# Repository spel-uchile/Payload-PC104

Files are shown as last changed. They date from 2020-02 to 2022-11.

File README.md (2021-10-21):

# Payload-PC104 #

This repository contains schematics and footprints of the PC104 standard for CubeSats' payloads. 
These designs are compatible with Eagle and KiCad PCB design software.
The footprints have also a suggested PCB boundary that facilitates the cable management of the CubeSat.

# KiCAD #

The KiCAD's schematic includes all the necessary pins assignments to speedup the payload design. The footprint already has the edge cuts done and it follows the PC104 specification.

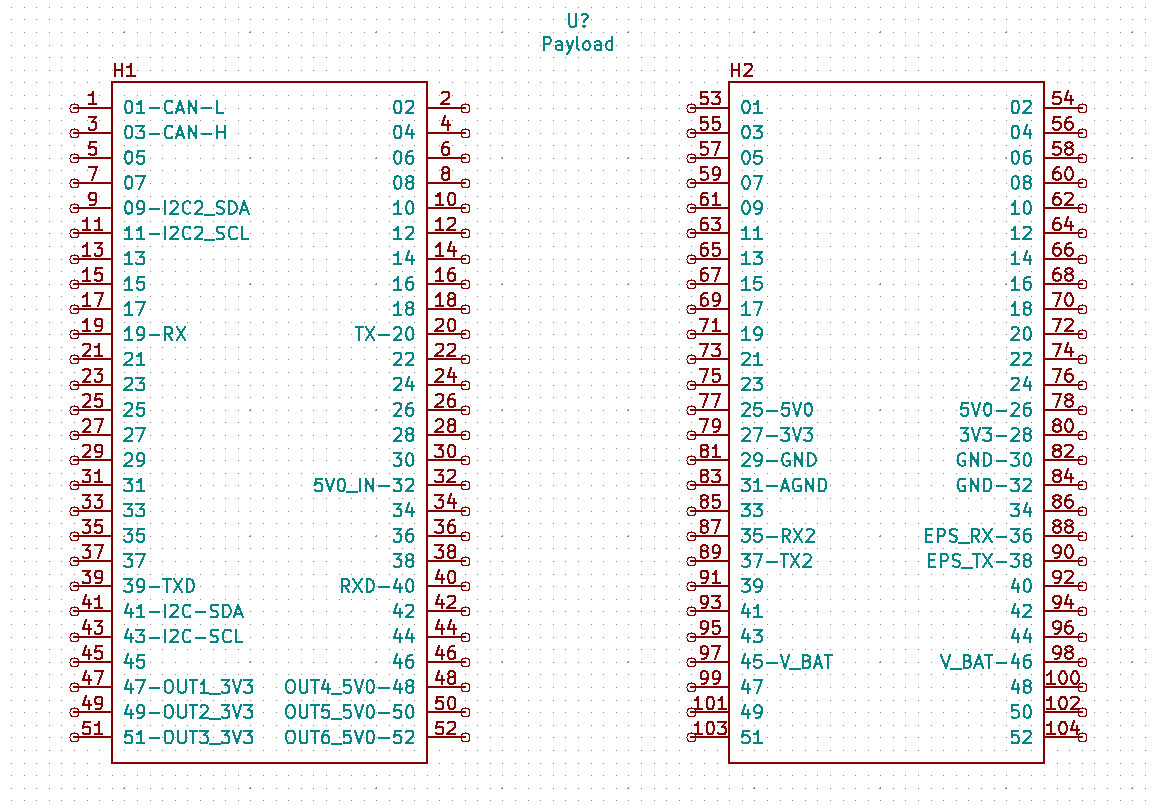
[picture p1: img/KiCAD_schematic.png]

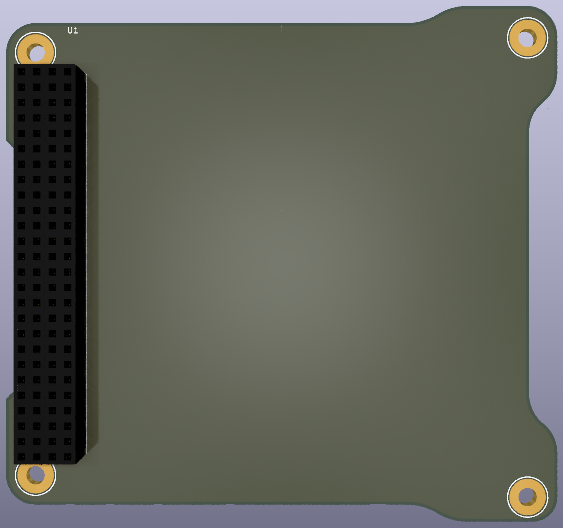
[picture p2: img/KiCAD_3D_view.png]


# Last update 10/21/2021# 
Output voltage pin update on StackBreakout with Molex picoBlade

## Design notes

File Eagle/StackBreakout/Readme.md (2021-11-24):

Readme - Stack Breakout

Stack Breakout - 4 capas

Historial

2021-11-24
Correción de error en conexión I2C v2. Los pines actuales son SCL (H1.9), SDA (H1.11). 
La versión anterior tiene las conexiones invertidas, es decir, el pin SCL estaba en H1.11, y SDA en H1.9.

2021-10-21
Se actualizan el orden los OUT pin de voltaje de acuerdo a la configuración de pinout de SPEL.

2020-08-12
Se incorpora conector con conexión I2C y UART.

2020-07-27 - V1.0
Se genera la placa de acuerdo a los diseños (dxf) enviados por Elías Obreque.
Se genera la placa usando cuatro capas
Se configurar parámetros genéricos (y más comunes) para el chequeo de errores (DRC - Design Rule Check)

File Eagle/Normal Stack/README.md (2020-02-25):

# Normal stack-PC104
This folder contains schematics and footprints of the PC104 standard for CubeSats' payloads with diferent dimension pad in the Stack component (only the pins used in SUCHAI project are edited)

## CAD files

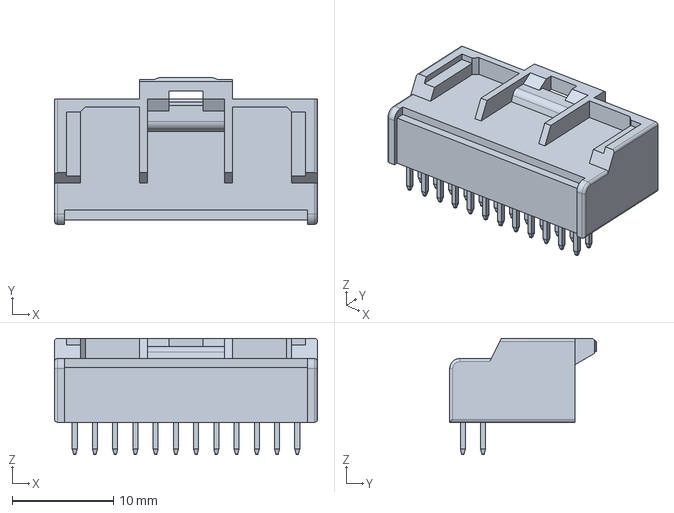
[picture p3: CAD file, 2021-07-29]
Eagle/StackBreakout/StackBreakoutConnection_4layers_V1.0_with_connector/MolexP24/2086592440.stp
26.0 x 14.5 x 11.5 mm

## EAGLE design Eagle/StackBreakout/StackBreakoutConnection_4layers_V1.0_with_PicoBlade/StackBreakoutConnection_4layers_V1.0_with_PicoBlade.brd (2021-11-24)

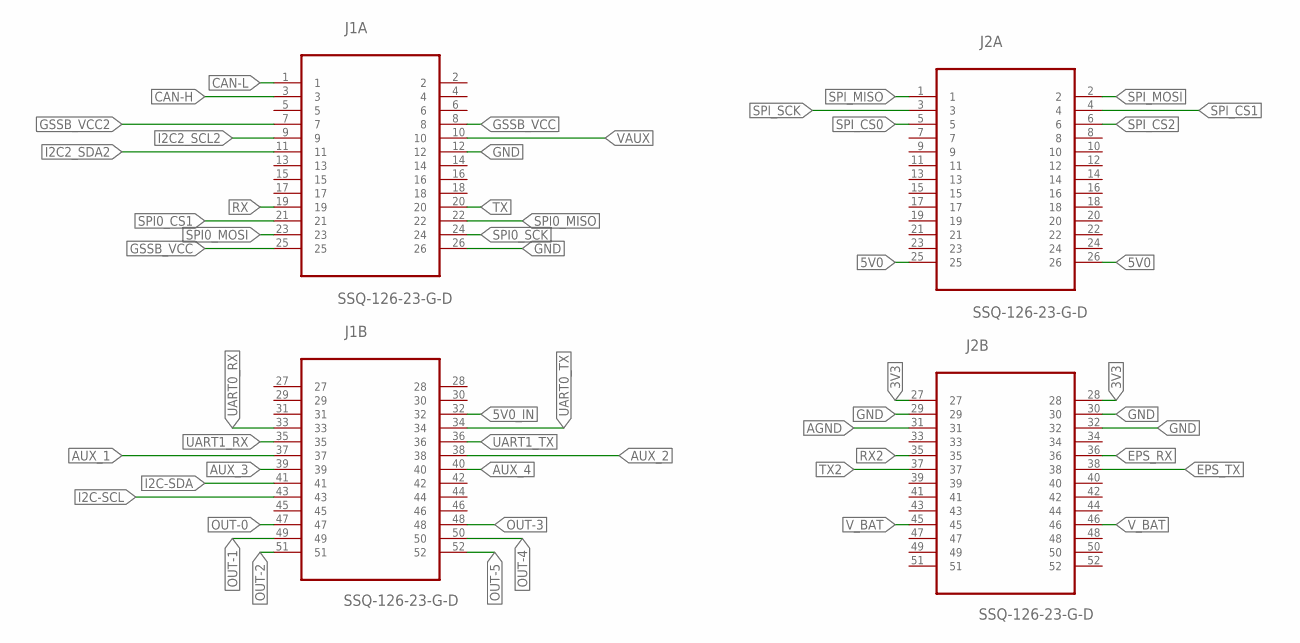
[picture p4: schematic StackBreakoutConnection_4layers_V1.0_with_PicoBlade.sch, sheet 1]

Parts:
J1, J2: SSQ-126-23-G-D; SAMTEC_SSQ-126-23-G-D

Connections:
3V3: J2.27, J2.28; also elsewhere on the board
5V0: J2.25, J2.26; also elsewhere on the board
5V0_IN: J1.32; also elsewhere on the board
AGND: J2.31; also elsewhere on the board
AUX_1: J1.37; also elsewhere on the board
AUX_2: J1.38; also elsewhere on the board
AUX_3: J1.39; also elsewhere on the board
AUX_4: J1.40; also elsewhere on the board
CAN-H: J1.3; also elsewhere on the board
CAN-L: J1.1; also elsewhere on the board
EPS_RX: J2.36; also elsewhere on the board
EPS_TX: J2.38; also elsewhere on the board
GND: J1.12, J1.26, J2.29, J2.30, J2.32; also elsewhere on the board
GSSB_VCC: J1.8, J1.25; also elsewhere on the board
GSSB_VCC2: J1.7; also elsewhere on the board
I2C2_SCL2: J1.9; also elsewhere on the board
I2C2_SDA2: J1.11; also elsewhere on the board
I2C-SCL: J1.43; also elsewhere on the board
I2C-SDA: J1.41; also elsewhere on the board
OUT-0: J1.47; also elsewhere on the board
OUT-1: J1.49; also elsewhere on the board
OUT-2: J1.51; also elsewhere on the board
OUT-3: J1.48; also elsewhere on the board
OUT-4: J1.50; also elsewhere on the board
OUT-5: J1.52; also elsewhere on the board
RX: J1.19
RX2: J2.35
SPI0_CS1: J1.21; also elsewhere on the board
SPI0_MISO: J1.22; also elsewhere on the board
SPI0_MOSI: J1.23; also elsewhere on the board
SPI0_SCK: J1.24; also elsewhere on the board
SPI_CS0: J2.5
SPI_CS1: J2.4
SPI_CS2: J2.6
SPI_MISO: J2.1
SPI_MOSI: J2.2
SPI_SCK: J2.3
TX: J1.20
TX2: J2.37
UART0_RX: J1.33; also elsewhere on the board
UART0_TX: J1.34; also elsewhere on the board
UART1_RX: J1.35; also elsewhere on the board
UART1_TX: J1.36; also elsewhere on the board
VAUX: J1.10; also elsewhere on the board
V_BAT: J2.45, J2.46; also elsewhere on the board

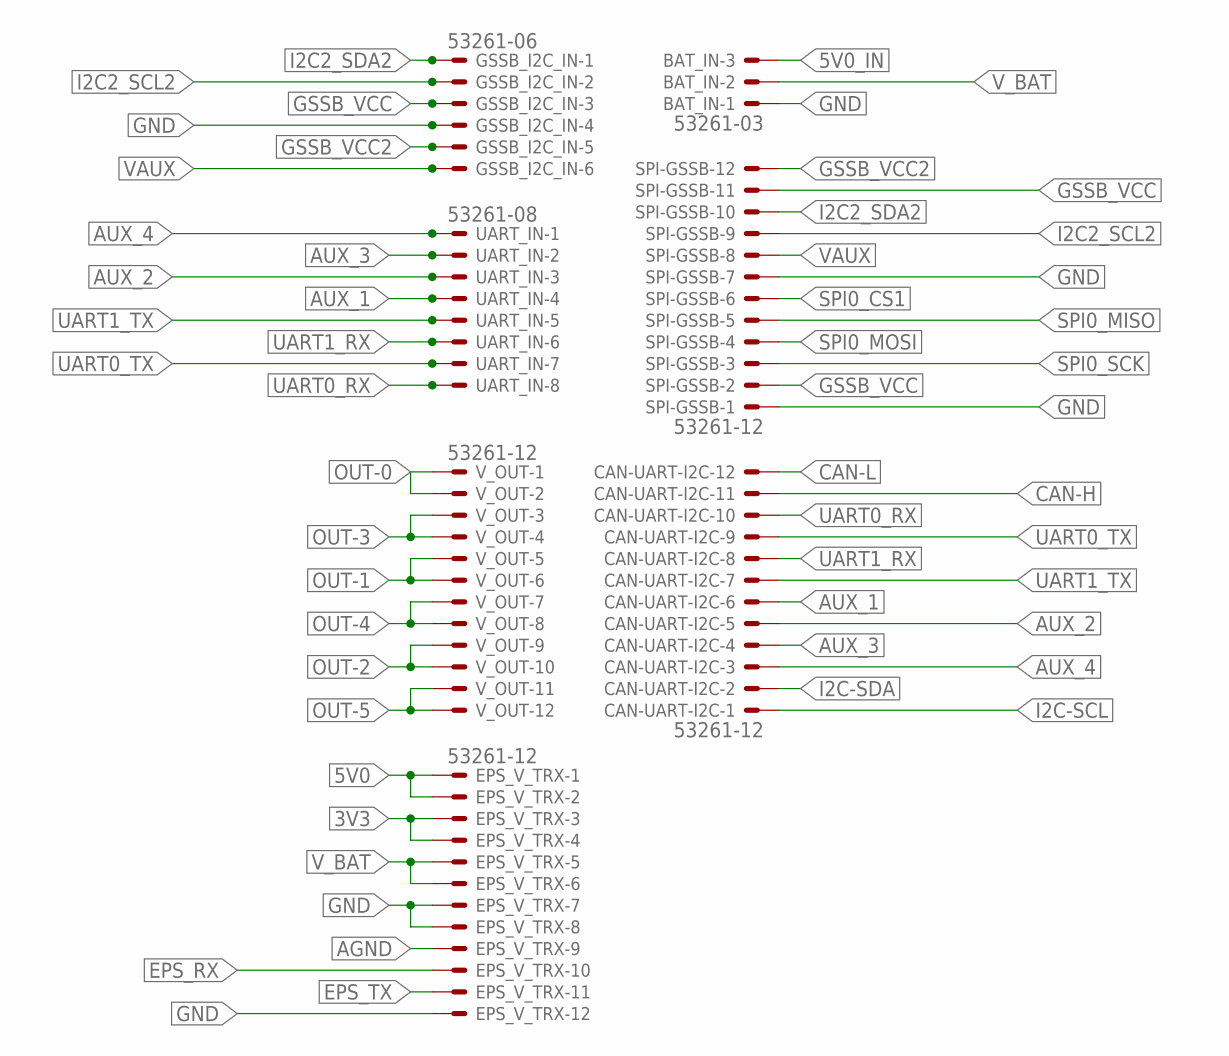
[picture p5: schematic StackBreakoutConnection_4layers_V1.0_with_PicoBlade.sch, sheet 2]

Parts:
BAT_IN: 53261-03
CAN-UART-I2C: 53261-12
EPS_V_TRX: 53261-12
GSSB_I2C_IN: 53261-06
SPI-GSSB: 53261-12
UART_IN: 53261-08
V_OUT: 53261-12

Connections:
3V3: EPS_V_TRX.3, EPS_V_TRX.4; also elsewhere on the board
5V0: EPS_V_TRX.1, EPS_V_TRX.2; also elsewhere on the board
5V0_IN: BAT_IN.3; also elsewhere on the board
AGND: EPS_V_TRX.9; also elsewhere on the board
AUX_1: CAN-UART-I2C.6, UART_IN.4; also elsewhere on the board
AUX_2: CAN-UART-I2C.5, UART_IN.3; also elsewhere on the board
AUX_3: CAN-UART-I2C.4, UART_IN.2; also elsewhere on the board
AUX_4: CAN-UART-I2C.3, UART_IN.1; also elsewhere on the board
CAN-H: CAN-UART-I2C.11; also elsewhere on the board
CAN-L: CAN-UART-I2C.12; also elsewhere on the board
EPS_RX: EPS_V_TRX.10; also elsewhere on the board
EPS_TX: EPS_V_TRX.11; also elsewhere on the board
GND: BAT_IN.1, EPS_V_TRX.7, EPS_V_TRX.8, EPS_V_TRX.12, GSSB_I2C_IN.4, SPI-GSSB.1, SPI-GSSB.7; also elsewhere on the board
GSSB_VCC: GSSB_I2C_IN.3, SPI-GSSB.2, SPI-GSSB.11; also elsewhere on the board
GSSB_VCC2: GSSB_I2C_IN.5, SPI-GSSB.12; also elsewhere on the board
I2C2_SCL2: GSSB_I2C_IN.2, SPI-GSSB.9; also elsewhere on the board
I2C2_SDA2: GSSB_I2C_IN.1, SPI-GSSB.10; also elsewhere on the board
I2C-SCL: CAN-UART-I2C.1; also elsewhere on the board
I2C-SDA: CAN-UART-I2C.2; also elsewhere on the board
OUT-0: V_OUT.1, V_OUT.2; also elsewhere on the board
OUT-1: V_OUT.5, V_OUT.6; also elsewhere on the board
OUT-2: V_OUT.9, V_OUT.10; also elsewhere on the board
OUT-3: V_OUT.3, V_OUT.4; also elsewhere on the board
OUT-4: V_OUT.7, V_OUT.8; also elsewhere on the board
OUT-5: V_OUT.11, V_OUT.12; also elsewhere on the board
SPI0_CS1: SPI-GSSB.6; also elsewhere on the board
SPI0_MISO: SPI-GSSB.5; also elsewhere on the board
SPI0_MOSI: SPI-GSSB.4; also elsewhere on the board
SPI0_SCK: SPI-GSSB.3; also elsewhere on the board
UART0_RX: CAN-UART-I2C.10, UART_IN.8; also elsewhere on the board
UART0_TX: CAN-UART-I2C.9, UART_IN.7; also elsewhere on the board
UART1_RX: CAN-UART-I2C.8, UART_IN.6; also elsewhere on the board
UART1_TX: CAN-UART-I2C.7, UART_IN.5; also elsewhere on the board
VAUX: GSSB_I2C_IN.6, SPI-GSSB.8; also elsewhere on the board
V_BAT: BAT_IN.2, EPS_V_TRX.5, EPS_V_TRX.6; also elsewhere on the board

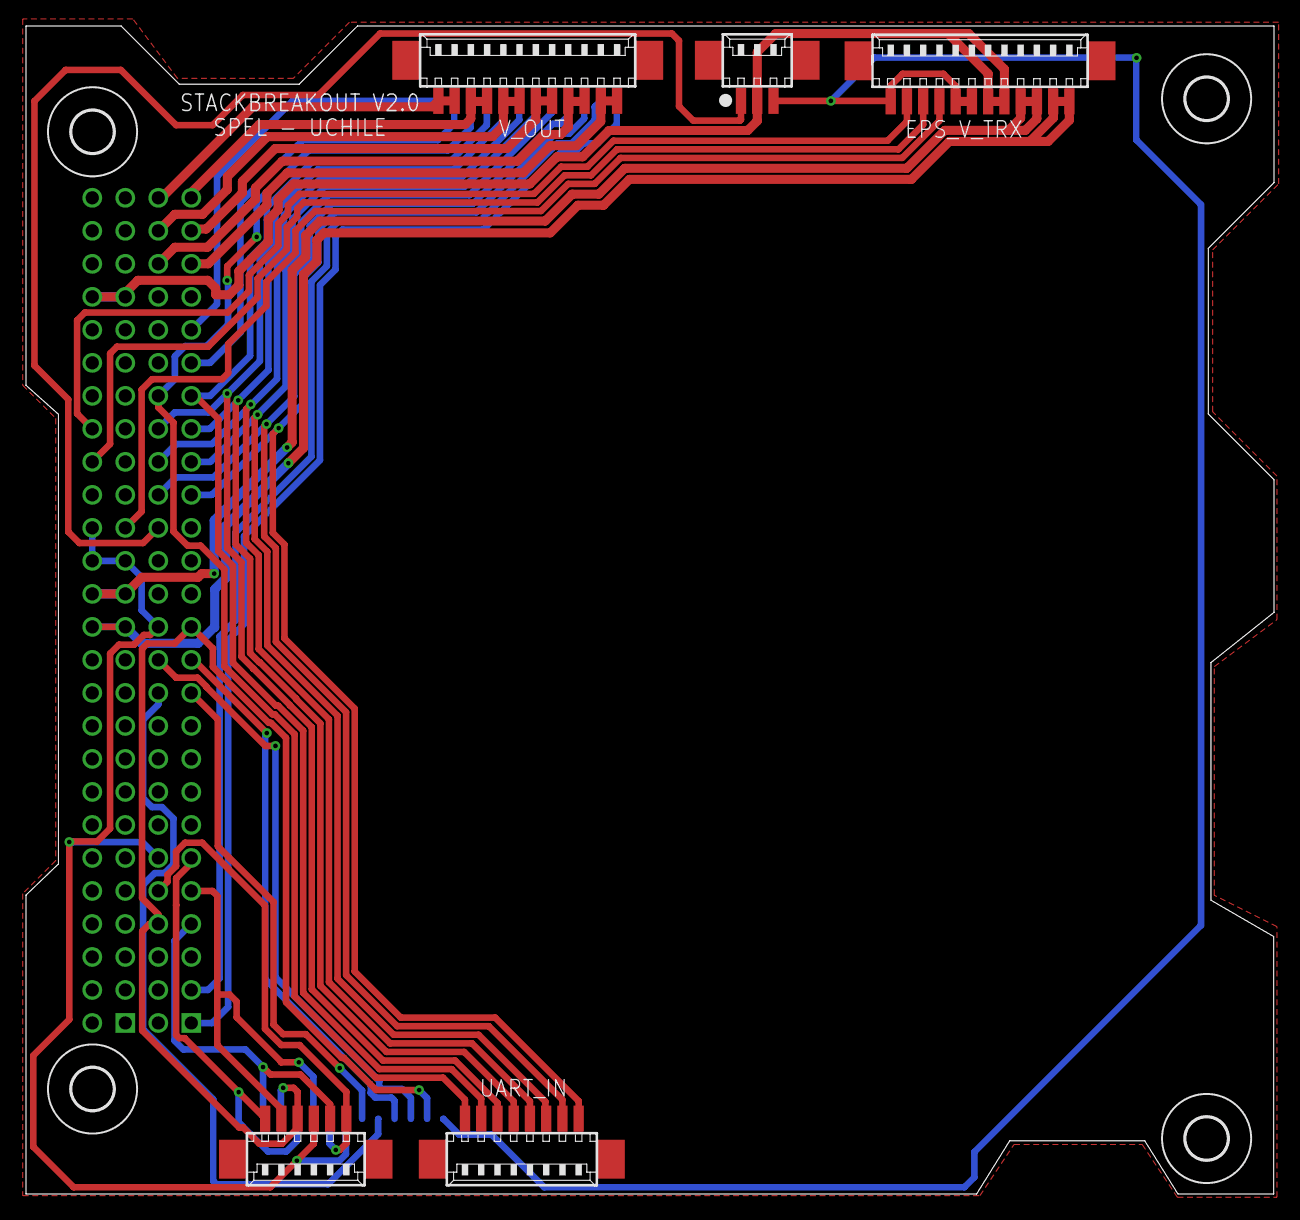
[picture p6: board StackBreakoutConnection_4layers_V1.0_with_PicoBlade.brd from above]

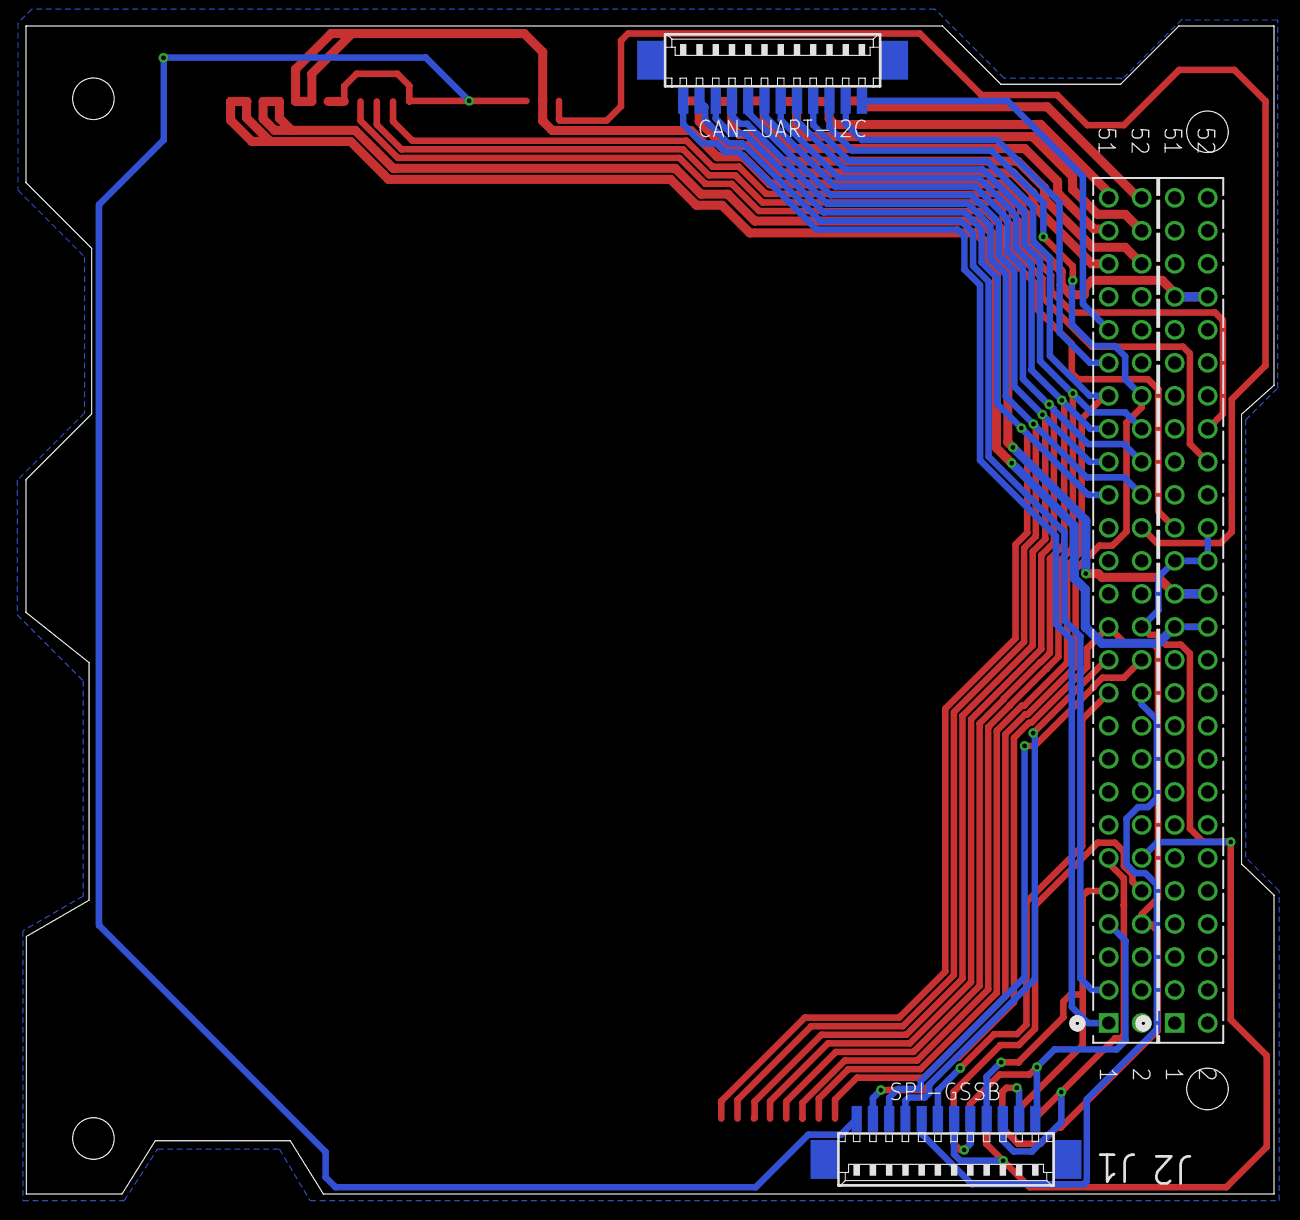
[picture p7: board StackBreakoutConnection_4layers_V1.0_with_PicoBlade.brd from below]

Board: 4 copper layers, 96.0 x 89.9 mm, 13 parts (4 on the bottom side), 35 nets.

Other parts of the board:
GND: 3,2
U$1, U$2, U$4: 3,2

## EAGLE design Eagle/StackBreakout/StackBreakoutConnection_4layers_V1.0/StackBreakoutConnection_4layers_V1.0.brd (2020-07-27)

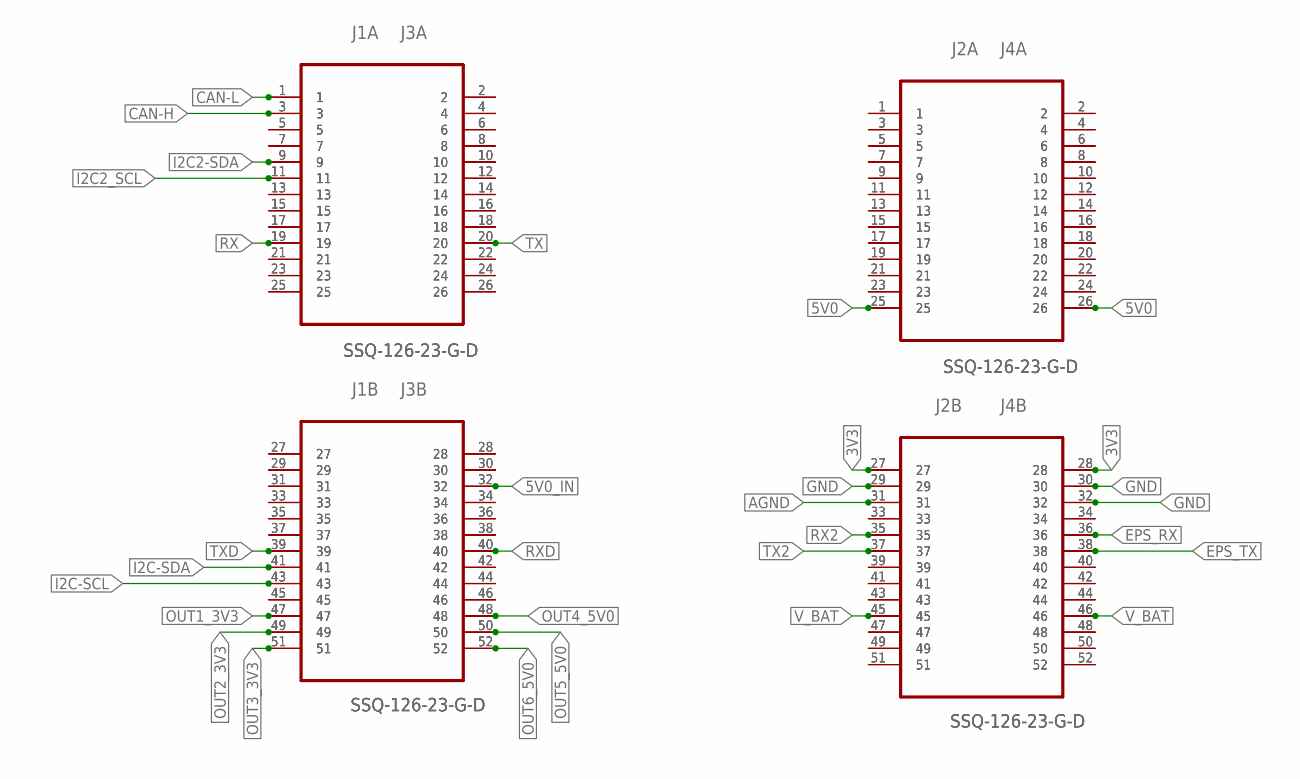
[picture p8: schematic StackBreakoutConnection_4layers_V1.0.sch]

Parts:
J1, J2, J3, J4: SSQ-126-23-G-D; SAMTEC_SSQ-126-23-G-D

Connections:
3V3: J2.27, J2.28, J4.27, J4.28
5V0: J2.25, J2.26, J4.25, J4.26
5V0_IN: J1.32, J3.32
AGND: J2.31, J4.31
CAN-H: J1.3, J3.3
CAN-L: J1.1, J3.1
EPS_RX: J2.36, J4.36
EPS_TX: J2.38, J4.38
GND: J2.29, J2.30, J2.32, J4.29, J4.30, J4.32
I2C2-SDA: J1.9, J3.9
I2C2_SCL: J1.11, J3.11
I2C-SCL: J1.43, J3.43
I2C-SDA: J1.41, J3.41
unnamed: J1.5, J3.5
unnamed: J1.7, J3.7
unnamed: J1.13, J3.13
unnamed: J1.15, J3.15
unnamed: J1.17, J3.17
unnamed: J1.21, J3.21
unnamed: J1.23, J3.23
unnamed: J1.25, J3.25
unnamed: J1.2, J3.2
unnamed: J1.4, J3.4
unnamed: J1.6, J3.6
unnamed: J1.8, J3.8
unnamed: J1.10, J3.10
unnamed: J1.12, J3.12
unnamed: J1.14, J3.14
unnamed: J1.16, J3.16
unnamed: J1.18, J3.18
unnamed: J1.22, J3.22
unnamed: J1.24, J3.24
unnamed: J1.26, J3.26
unnamed: J1.27, J3.27
unnamed: J1.29, J3.29
unnamed: J1.31, J3.31
unnamed: J1.33, J3.33
unnamed: J1.35, J3.35
unnamed: J1.37, J3.37
unnamed: J1.45, J3.45
unnamed: J1.28, J3.28
unnamed: J1.30, J3.30
unnamed: J1.34, J3.34
unnamed: J1.36, J3.36
unnamed: J1.38, J3.38
unnamed: J1.42, J3.42
unnamed: J1.44, J3.44
unnamed: J1.46, J3.46
unnamed: J2.1, J4.1
unnamed: J2.3, J4.3
unnamed: J2.5, J4.5
unnamed: J2.7, J4.7
unnamed: J2.9, J4.9
unnamed: J2.11, J4.11
unnamed: J2.13, J4.13
unnamed: J2.15, J4.15
unnamed: J2.17, J4.17
unnamed: J2.19, J4.19
unnamed: J2.21, J4.21
unnamed: J2.23, J4.23
unnamed: J2.2, J4.2
unnamed: J2.4, J4.4
unnamed: J2.6, J4.6
unnamed: J2.8, J4.8
unnamed: J2.10, J4.10
unnamed: J2.12, J4.12
unnamed: J2.14, J4.14
unnamed: J2.16, J4.16
unnamed: J2.18, J4.18
unnamed: J2.20, J4.20
unnamed: J2.22, J4.22
unnamed: J2.24, J4.24
unnamed: J2.33, J4.33
unnamed: J2.39, J4.39
unnamed: J2.41, J4.41
unnamed: J2.43, J4.43
unnamed: J2.47, J4.47
unnamed: J2.49, J4.49
unnamed: J2.51, J4.51
unnamed: J2.34, J4.34
unnamed: J2.40, J4.40
unnamed: J2.42, J4.42
unnamed: J2.44, J4.44
unnamed: J2.48, J4.48
unnamed: J2.50, J4.50
unnamed: J2.52, J4.52
OUT1_3V3: J1.47, J3.47
OUT2_3V3: J1.49, J3.49
OUT3_3V3: J1.51, J3.51
OUT4_5V0: J1.48, J3.48
OUT5_5V0: J1.50, J3.50
OUT6_5V0: J1.52, J3.52
RX: J1.19, J3.19
RX2: J2.35, J4.35
RXD: J1.40, J3.40
TX: J1.20, J3.20
TX2: J2.37, J4.37
TXD: J1.39, J3.39
V_BAT: J2.45, J2.46, J4.45, J4.46

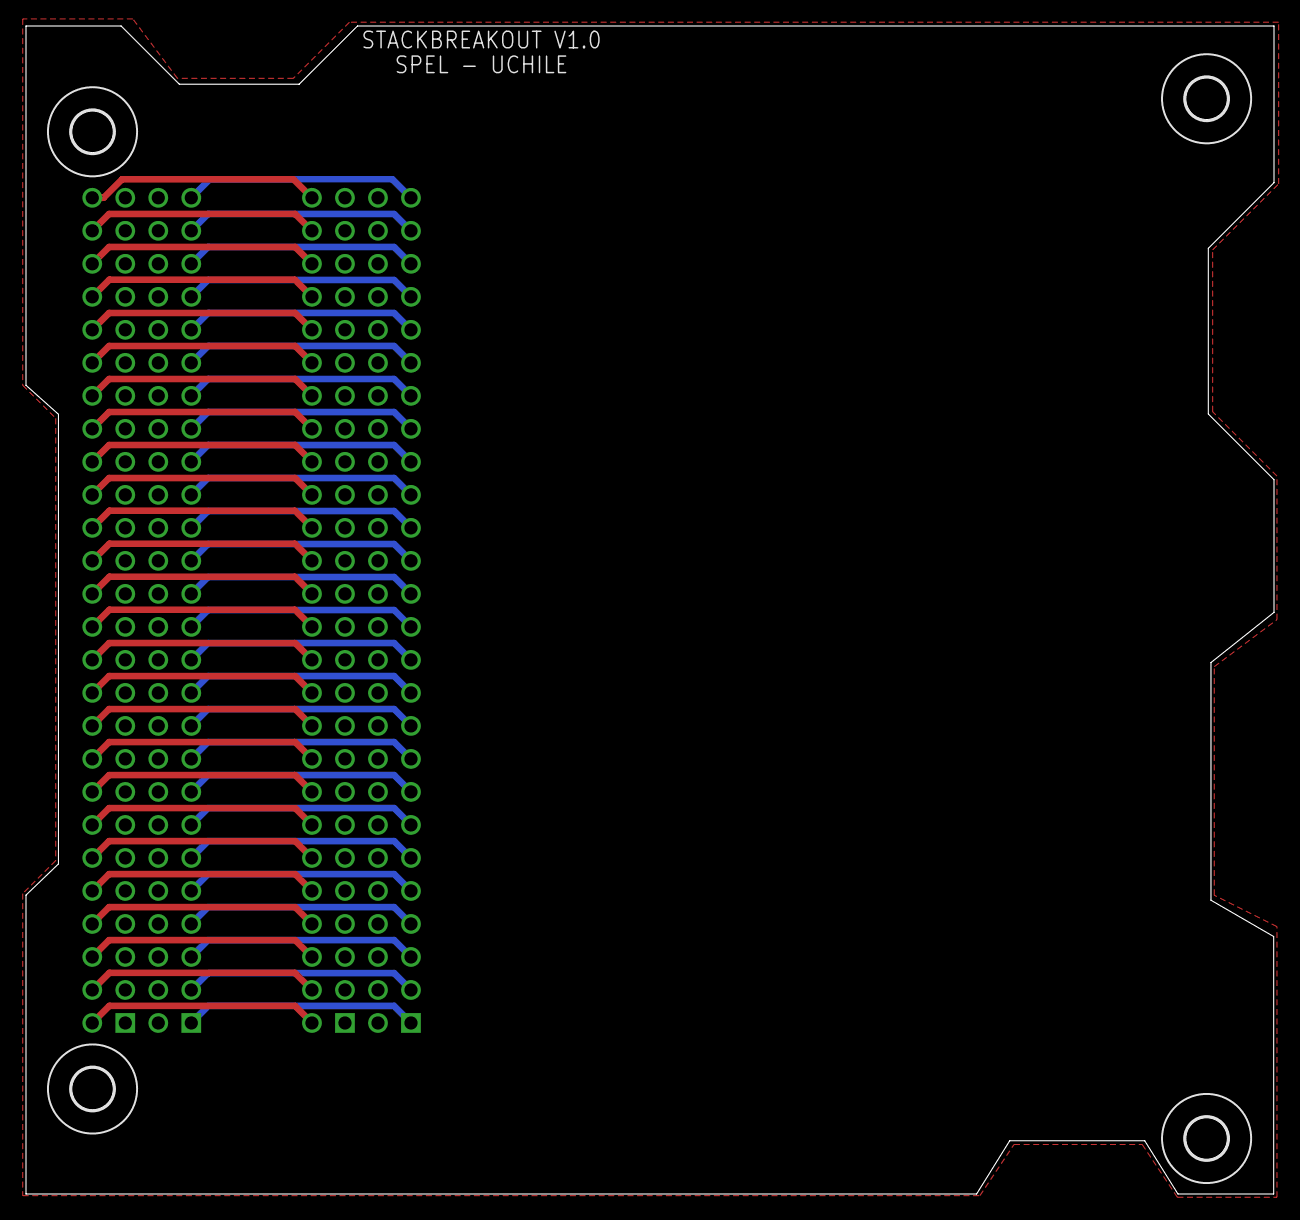
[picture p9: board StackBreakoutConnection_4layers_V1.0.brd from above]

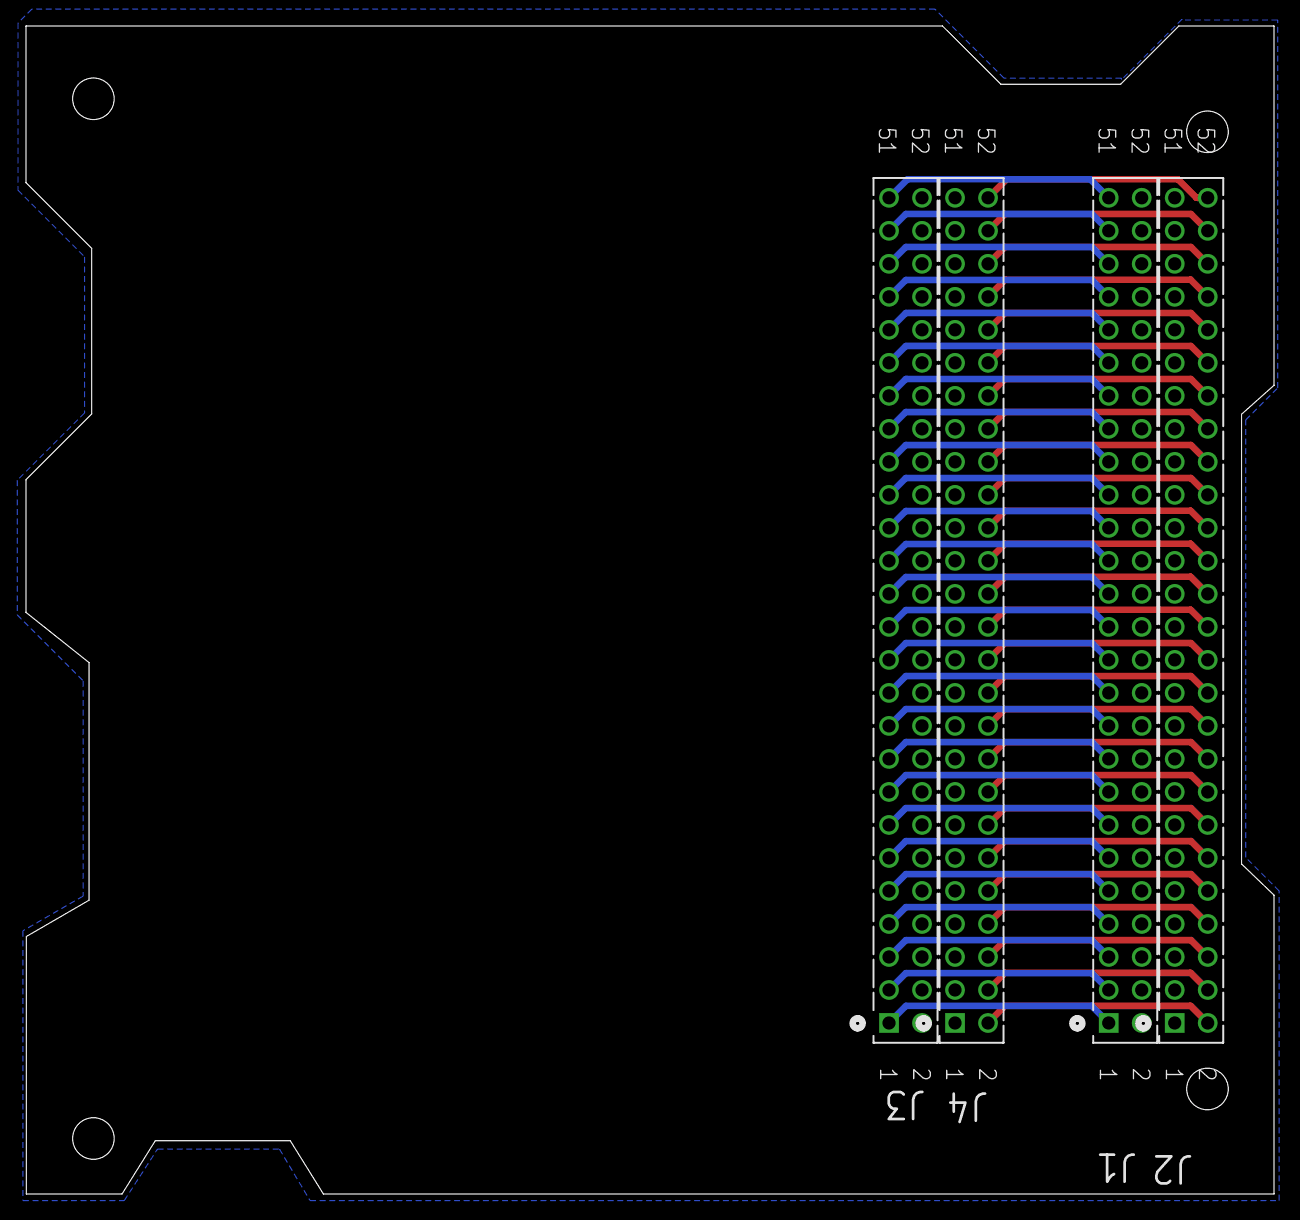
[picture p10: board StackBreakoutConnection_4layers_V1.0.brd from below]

Board: 4 copper layers, 96.0 x 89.9 mm, 8 parts (4 on the bottom side), 99 nets.

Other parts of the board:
U$1, U$2, U$3, U$4: 3,2

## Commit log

2018-11-14 Added a KiCad library for the payload template, following the CubeSat and PC104 standards. It includes an schematic with the SUCHAI 2 and 3 pinout and a footprint.
2018-11-14 Added silk mask with the boundaries of the stack and the mechanical holes. Also changed the first pin's shape from circular to rectangular.
2018-11-15 Eagle library_ PCB
2018-11-16 Changed footprint's outer lines from F.SilkS layer to Edge.Cuts. Also increased drill size of the mechanical holes.
2018-11-20 Increased the pad's size of the mechanical drills.
2018-11-20 Fixed error in pin spacing (changed from 2.56 mm to 2.54 mm).
2018-11-28 Changed NPTH to Through-holes, so that they can be connected to ground.
2019-06-11 Increased drill and pad size.
2019-07-05 Updated the symbol and footprint of the PC104 standard.
2020-02-25 Update to Eagle version of PC104 stack schematic and dimensions
2020-02-25 Pad-Pinout with 1.75 mm d
2020-04-08 Conexiones entre Stack
    [StackBreakoutConnection.brd, StackBreakoutConnection.sch]
2020-07-27 First version of 4 layers Stack Breakout PCB
    [StackBreakoutConnection_4layers_V1.0.brd, StackBreakoutConnection_4layers_V1.0.sch]
2020-08-25 Corrección de Aux_x
    [StackBreakoutConnection_4layers_V1.0_with_connector.brd, StackBreakoutConnection_4layers_V1.0_with_connector.sch]
2021-07-29 PC104 picoblade
    [2086592440.stp, StackBreakoutConnection_4layers_V1.0_with_PicoBlade.brd, StackBreakoutConnection_4layers_V1.0_with_PicoBlade.sch]
2021-10-21 Output voltage pin update
    [StackBreakoutConnection_4layers_V1.0_with_PicoBlade.brd, StackBreakoutConnection_4layers_V1.0_with_PicoBlade.sch]
2021-11-24 update i2c pinout
    [StackBreakoutConnection_4layers_V1.0_with_PicoBlade.brd, StackBreakoutConnection_4layers_V1.0_with_PicoBlade.sch]
2022-11-02 Added more space for cable management and smoothened the edges.
2022-11-02 Updated the footprint for the latest KiCAD version.

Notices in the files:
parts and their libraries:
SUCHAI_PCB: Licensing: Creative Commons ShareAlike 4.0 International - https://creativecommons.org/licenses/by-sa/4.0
